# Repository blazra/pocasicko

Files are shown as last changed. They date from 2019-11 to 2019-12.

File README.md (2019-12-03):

# Počasíčko

LoRa node with e-paper display and BME680
- Murata CMWX1ZZABZ-091: Semtech SX1276 + STM32L072
- Bosch Sensortec BME680 measures pressure, humidity, temperature and Volatile Organic Compounds (VOC)
- Waveshare 4.2" EPD 400x300
- Powered from three AA batteries

Revision 1 known issues:
- Missing divider for battery voltage monitoring
- Unable to wake-up from standby using BUTTON_A (WKUP1), because pull-ups are disconnected in standby mode

[Schematic](./pcb/revision_1/pocasicko-schematic.pdf)

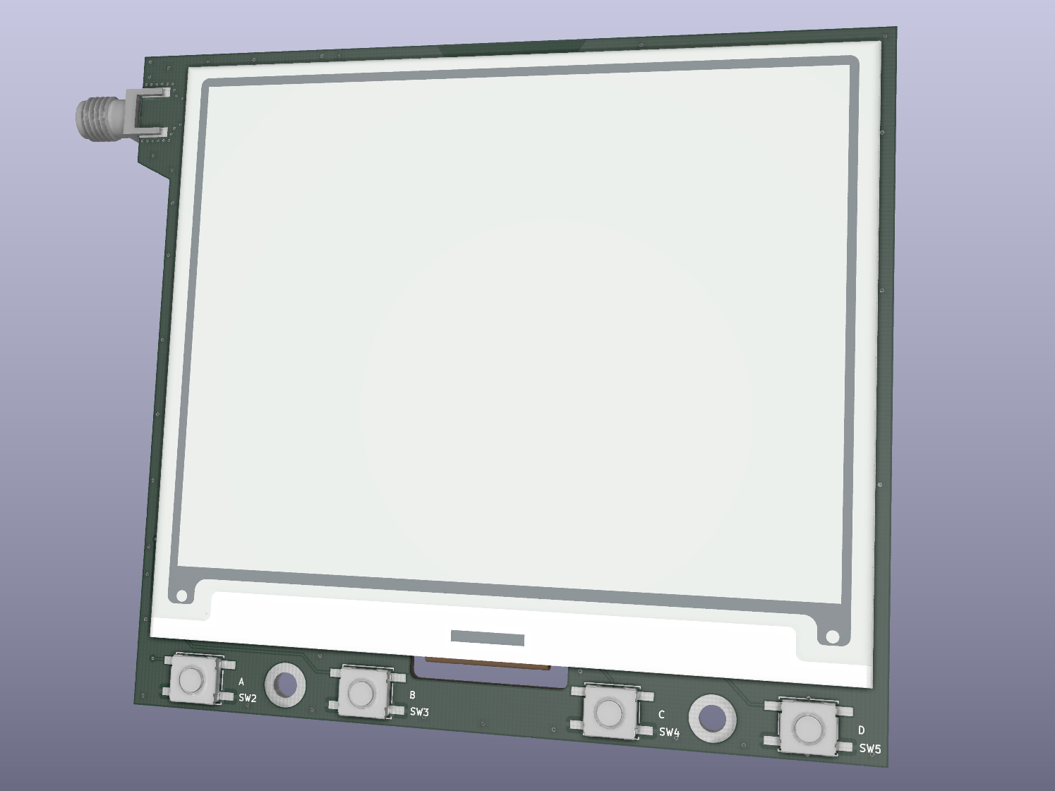
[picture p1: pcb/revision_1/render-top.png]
Front pcb render

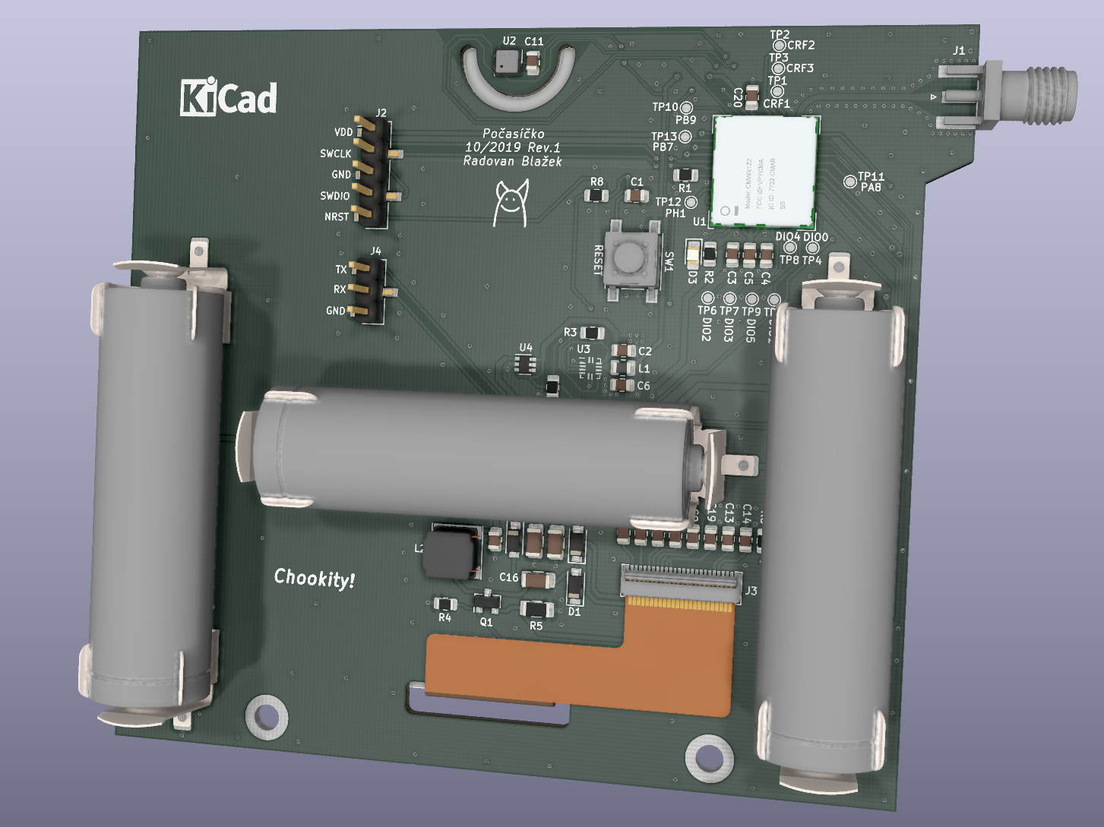
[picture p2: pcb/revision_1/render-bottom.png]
Back pcb render


---
Počasíčko means little weather in Czech

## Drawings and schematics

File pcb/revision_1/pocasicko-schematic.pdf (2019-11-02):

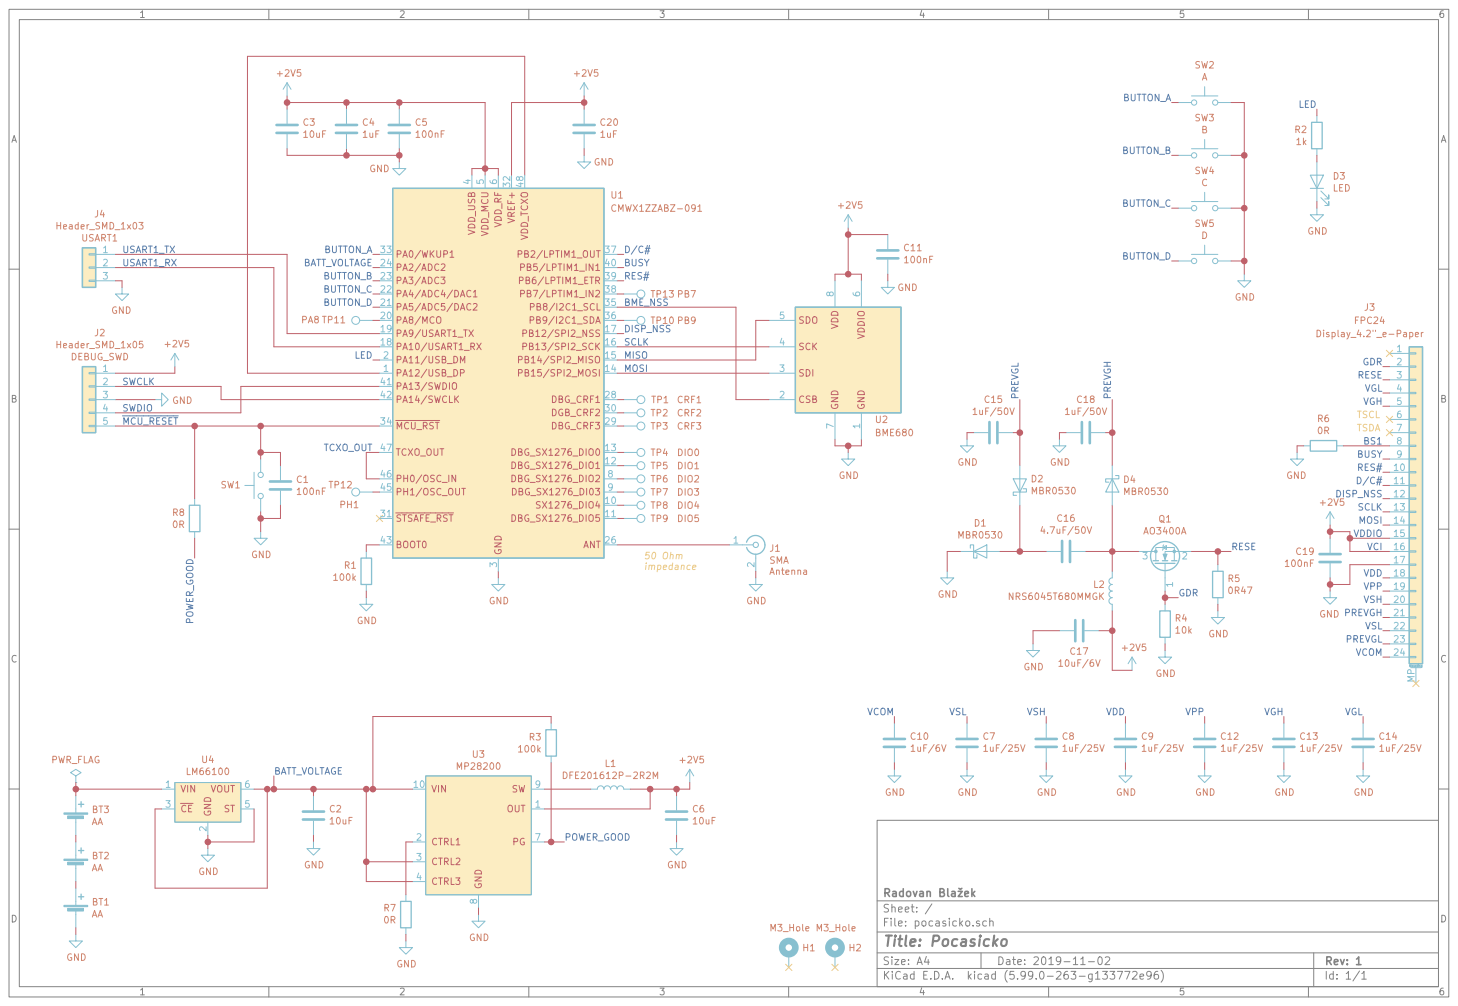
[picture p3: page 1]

1 CSB 2 SDI 3 SCK 4 SDO 5 VDDIO

File: pocasicko.sch Sheet: / Radovan Blaek GND

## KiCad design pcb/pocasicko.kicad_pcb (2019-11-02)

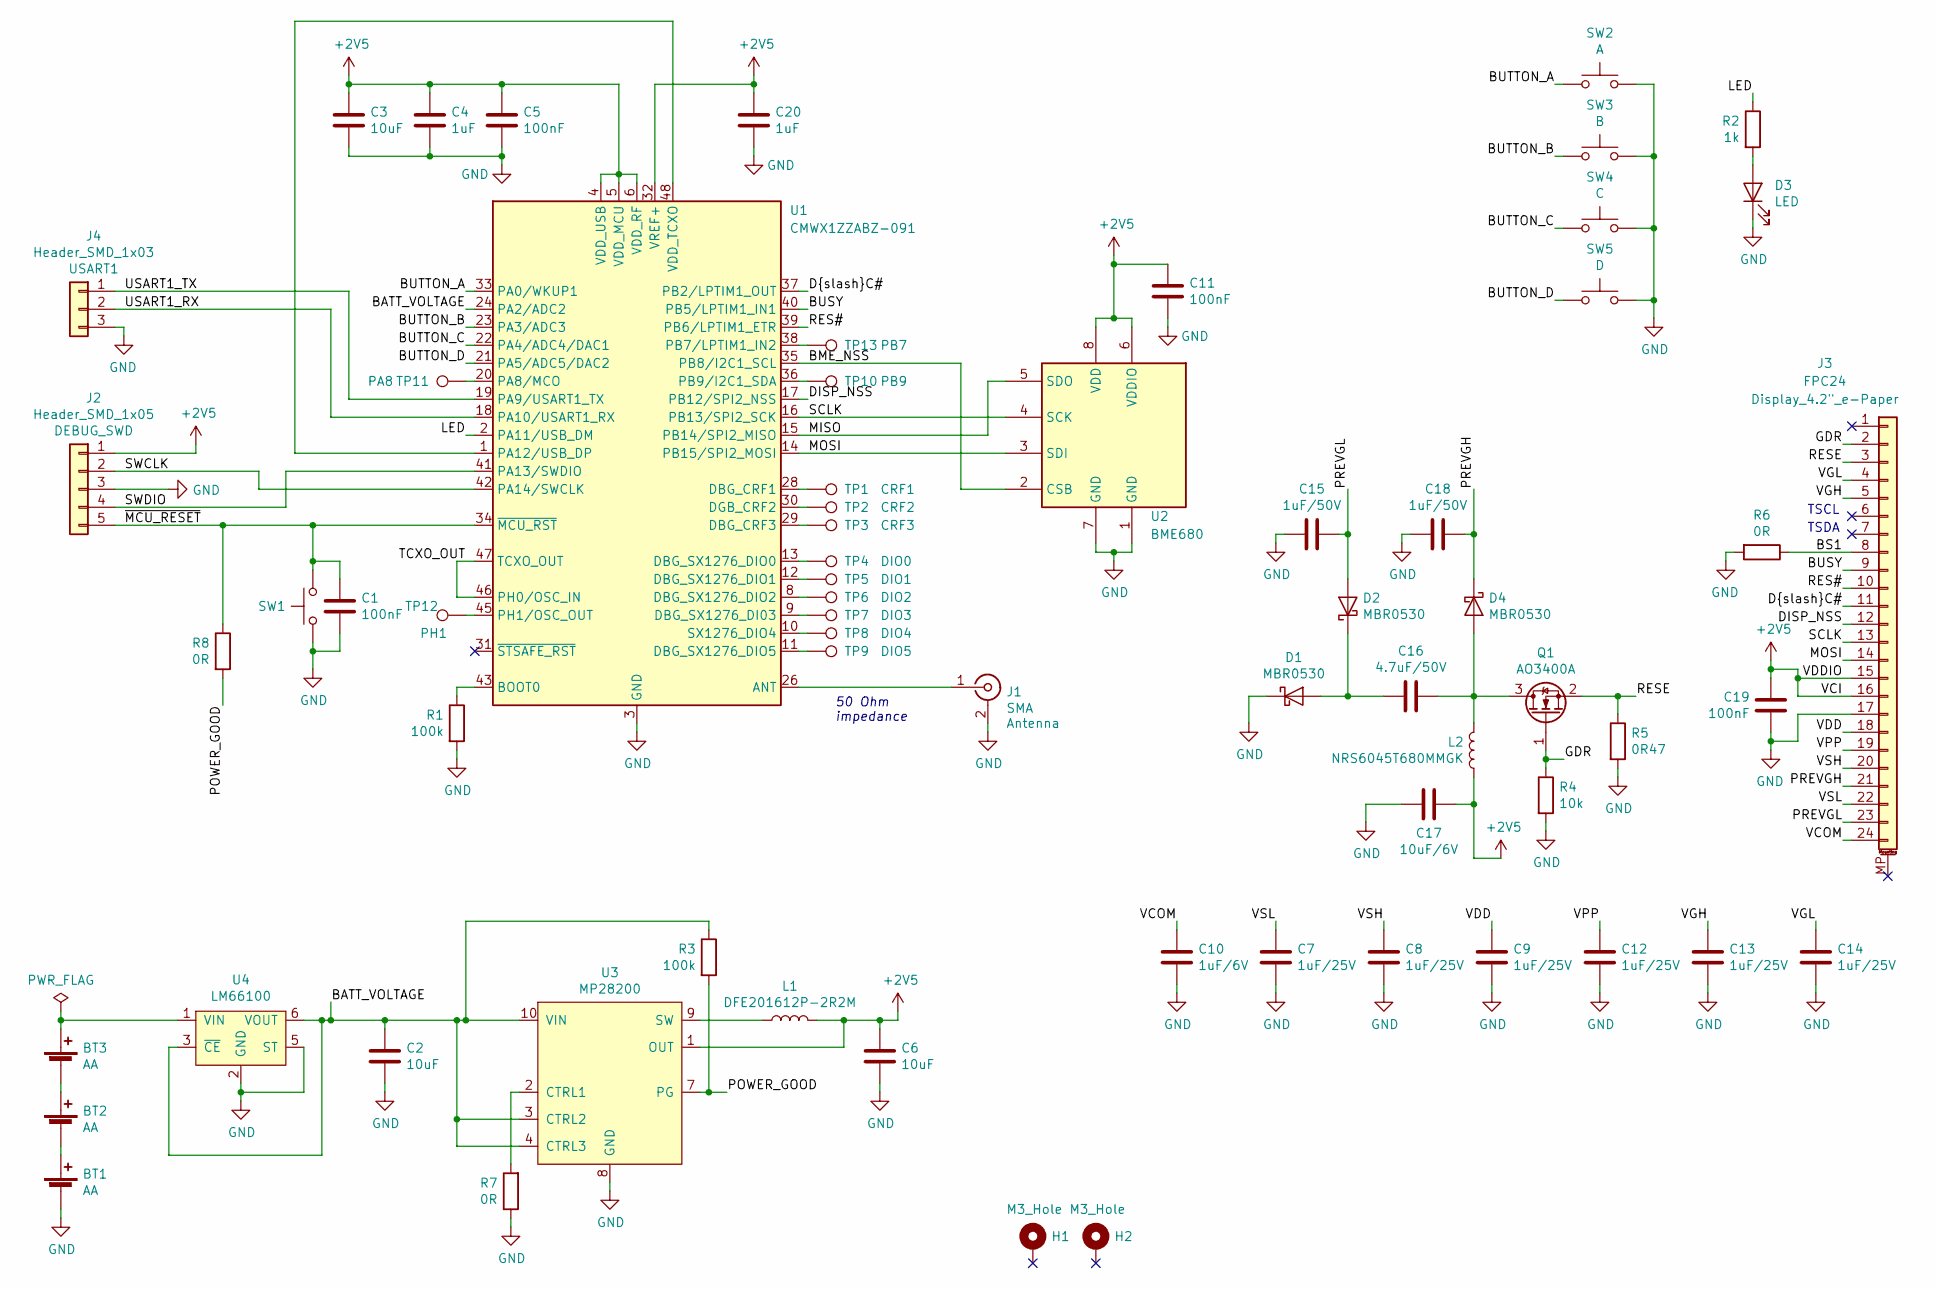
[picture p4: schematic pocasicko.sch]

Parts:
BT1, BT2, BT3: AA; BatteryHolder_Keystone_53_1xAA
C1, C5, C11, C19: 100nF; C_0805_2012Metric
C2, C3, C6: 10uF; C_0805_2012Metric
C4, C20: 1uF; C_0805_2012Metric
C7, C8, C9, C12, C13, C14: 1uF/25V; C_0805_2012Metric
C10: 1uF/6V; C_0805_2012Metric
C15, C18: 1uF/50V; C_1206_3216Metric
C16: 4.7uF/50V; C_1206_3216Metric
C17: 10uF/6V; C_0805_2012Metric
D1, D2, D4: MBR0530; D_SOD-123
D3: LED; LED_0805_2012Metric_Castellated
H1, H2: M3_Hole; MountingHole_3.2mm_M3_DIN965_Pad
J1: SMA; SMA_Samtec_SMA-J-P-H-ST-EM1_EdgeMount
J2: Header_SMD_1x05; PinHeader_1x05_P2.54mm_Vertical_SMD_Pin1Left
J3: FPC24; Waveshare_EPD_4.2_Amphenol_SFV24R-4STBE1HLF
J4: Header_SMD_1x03; PinHeader_1x03_P2.54mm_Vertical_SMD_Pin1Left
L1: DFE201612P-2R2M; L_0806_2016Metric
L2: NRS6045T680MMGK; L_Taiyo-Yuden_NR-60xx
Q1: AO3400A; SOT-23
R1, R3: 100k; R_0805_2012Metric
R2: 1k; R_0805_2012Metric
R4: 10k; R_0805_2012Metric
R5: 0R47; R_1206_3216Metric
R6, R7, R8: 0R; R_0805_2012Metric
SW1: RESET; SW_Push_1P1T_NO_6x6mm_H9.5mm
SW2: A; SW_SPST_EVQQ2
SW3: B; SW_SPST_EVQQ2
SW4: C; SW_SPST_EVQQ2
SW5: D; SW_SPST_EVQQ2
TP1: CRF1; TestPoint_Pad_D1.0mm
TP2: CRF2; TestPoint_Pad_D1.0mm
TP3: CRF3; TestPoint_Pad_D1.0mm
TP4: DIO0; TestPoint_Pad_D1.0mm
TP5: DIO1; TestPoint_Pad_D1.0mm
TP6: DIO2; TestPoint_Pad_D1.0mm
TP7: DIO3; TestPoint_Pad_D1.0mm
TP8: DIO4; TestPoint_Pad_D1.0mm
TP9: DIO5; TestPoint_Pad_D1.0mm
TP10: PB9; TestPoint_Pad_D1.0mm
TP11: PA8; TestPoint_Pad_D1.0mm
TP12: PH1; TestPoint_Pad_D1.0mm
TP13: PB7; TestPoint_Pad_D1.0mm
U1: CMWX1ZZABZ-091; CMWX1ZZABZ
U2: BME680; Bosch_LGA-8_3x3mm_P0.8mm_ClockwisePinNumbering
U3: MP28200; QFN-12_2x2_Pitch0.4mm
U4: LM66100; SOT-363_SC-70-6

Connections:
+2V5: C3.2, C4.2, C5.2, C6.2, C11.2, C17.2, C19.2, C20.2, J2.1, J3.15, J3.16, L1.2, L2.1, U1.4 (VDD_USB), U1.5 (VDD_MCU), U1.6 (VDD_RF), U1.32 (VREF+), U2.6 (VDDIO), U2.8 (VDD), U3.1 (OUT)
/BATT_VOLTAGE: C2.2, R3.1, U1.24 (PA2/ADC2), U3.3 (CTRL2), U3.4 (CTRL3), U3.10 (VIN), U4.3 (~CE), U4.6 (VOUT)
/BME_NSS: U1.35 (PB8/I2C1_SCL), U2.2 (CSB)
/BS1: J3.8, R6.1
/BUSY: J3.9, U1.40 (PB5/LPTIM1_IN1)
/BUTTON_A: SW2.1, U1.33 (PA0/WKUP1)
/BUTTON_B: SW3.1, U1.23 (PA3/ADC3)
/BUTTON_C: SW4.1, U1.22 (PA4/ADC4/DAC1)
/BUTTON_D: SW5.1, U1.21 (PA5/ADC5/DAC2)
/DISP_NSS: J3.12, U1.17 (PB12/SPI2_NSS)
/D/C#: J3.11, U1.37 (PB2/LPTIM1_OUT)
/GDR: J3.2, Q1.1 (G), R4.1
/LED: R2.1, U1.2 (PA11/USB_DM)
/MISO: U1.15 (PB14/SPI2_MISO), U2.5 (SDO)
/MOSI: J3.14, U1.14 (PB15/SPI2_MOSI), U2.3 (SDI)
/POWER_GOOD: R3.2, R8.2, U3.7 (PG)
/PREVGH: C18.1, D4.1 (K), J3.21
/PREVGL: C15.1, D2.2 (A), J3.23
/RES#: J3.10, U1.39 (PB6/LPTIM1_ETR)
/RESE: J3.3, Q1.2 (S), R5.1
/SCLK: J3.13, U1.16 (PB13/SPI2_SCK), U2.4 (SCK)
/SWCLK: J2.2, U1.42 (PA14/SWCLK)
/SWDIO: J2.4, U1.41 (PA13/SWDIO)
/TCXO_OUT: U1.46 (PH0/OSC_IN), U1.47 (TCXO_OUT)
/USART1_RX: J4.2, U1.18 (PA10/USART1_RX)
/USART1_TX: J4.1, U1.19 (PA9/USART1_TX)
/VCOM: C10.2, J3.24
/VDD: C9.2, J3.18
/VGH: C13.2, J3.5
/VGL: C14.2, J3.4
/VPP: C12.2, J3.19
/VSH: C8.2, J3.20
/VSL: C7.2, J3.22
/~MCU_RESET: C1.1, J2.5, R8.1, SW1.2, U1.34 (~MCU_RST)
GND: BT1.2 (-), C1.2, C2.1, C3.1, C4.1, C5.1, C6.1, C7.1, C8.1, C9.1, C10.1, C11.1, C12.1, C13.1, C14.1, C15.2, C17.1, C18.2, C19.1, C20.1, D1.1 (K), D3.1 (K), J1.2 (Ext), J2.3, J3.17, J4.3, R1.2, R4.2, R5.2, R6.2, R7.1, SW1.1, SW2.2, SW3.2, SW4.2, SW5.2, U1.3 (GND), U1.7 (GND), U1.25 (GND), U1.27 (GND), U1.44 (GND), U1.49 (GND), U1.50 (GND), U1.51 (GND), U1.52 (GND), U1.53 (GND), U1.54 (GND), U1.55 (GND), U1.56 (GND), U1.57 (GND), U2.1 (GND), U2.7 (GND), U3.5 (TP), U3.6 (TP), U3.8 (GND), U4.2 (GND), U4.5 (ST)
unnamed: BT1.1 (+), BT2.2 (-)
unnamed: BT2.1 (+), BT3.2 (-)
unnamed: BT3.1 (+), U4.1 (VIN)
unnamed: C16.1, D4.2 (A), L2.2, Q1.3 (D)
unnamed: C16.2, D1.2 (A), D2.1 (K)
unnamed: D3.2 (A), R2.2
unnamed: J1.1 (In), U1.26 (ANT)
unnamed: L1.1, U3.9 (SW)
unnamed: R1.1, U1.43 (BOOT0)
unnamed: R7.2, U3.2 (CTRL1)
unnamed: TP1.1, U1.28 (DBG_CRF1)
unnamed: TP2.1, U1.30 (DGB_CRF2)
unnamed: TP3.1, U1.29 (DBG_CRF3)
unnamed: TP4.1, U1.13 (DBG_SX1276_DIO0)
unnamed: TP5.1, U1.12 (DBG_SX1276_DIO1)
unnamed: TP6.1, U1.8 (DBG_SX1276_DIO2)
unnamed: TP7.1, U1.9 (DBG_SX1276_DI03)
unnamed: TP8.1, U1.10 (SX1276_DIO4)
unnamed: TP9.1, U1.11 (DBG_SX1276_DIO5)
unnamed: TP10.1, U1.36 (PB9/I2C1_SDA)
unnamed: TP11.1, U1.20 (PA8/MCO)
unnamed: TP12.1, U1.45 (PH1/OSC_OUT)
unnamed: TP13.1, U1.38 (PB7/LPTIM1_IN2)
unnamed: U1.1 (PA12/USB_DP), U1.48 (VDD_TCXO)

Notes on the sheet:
50 Ohm impedance
TSCL
TSDA

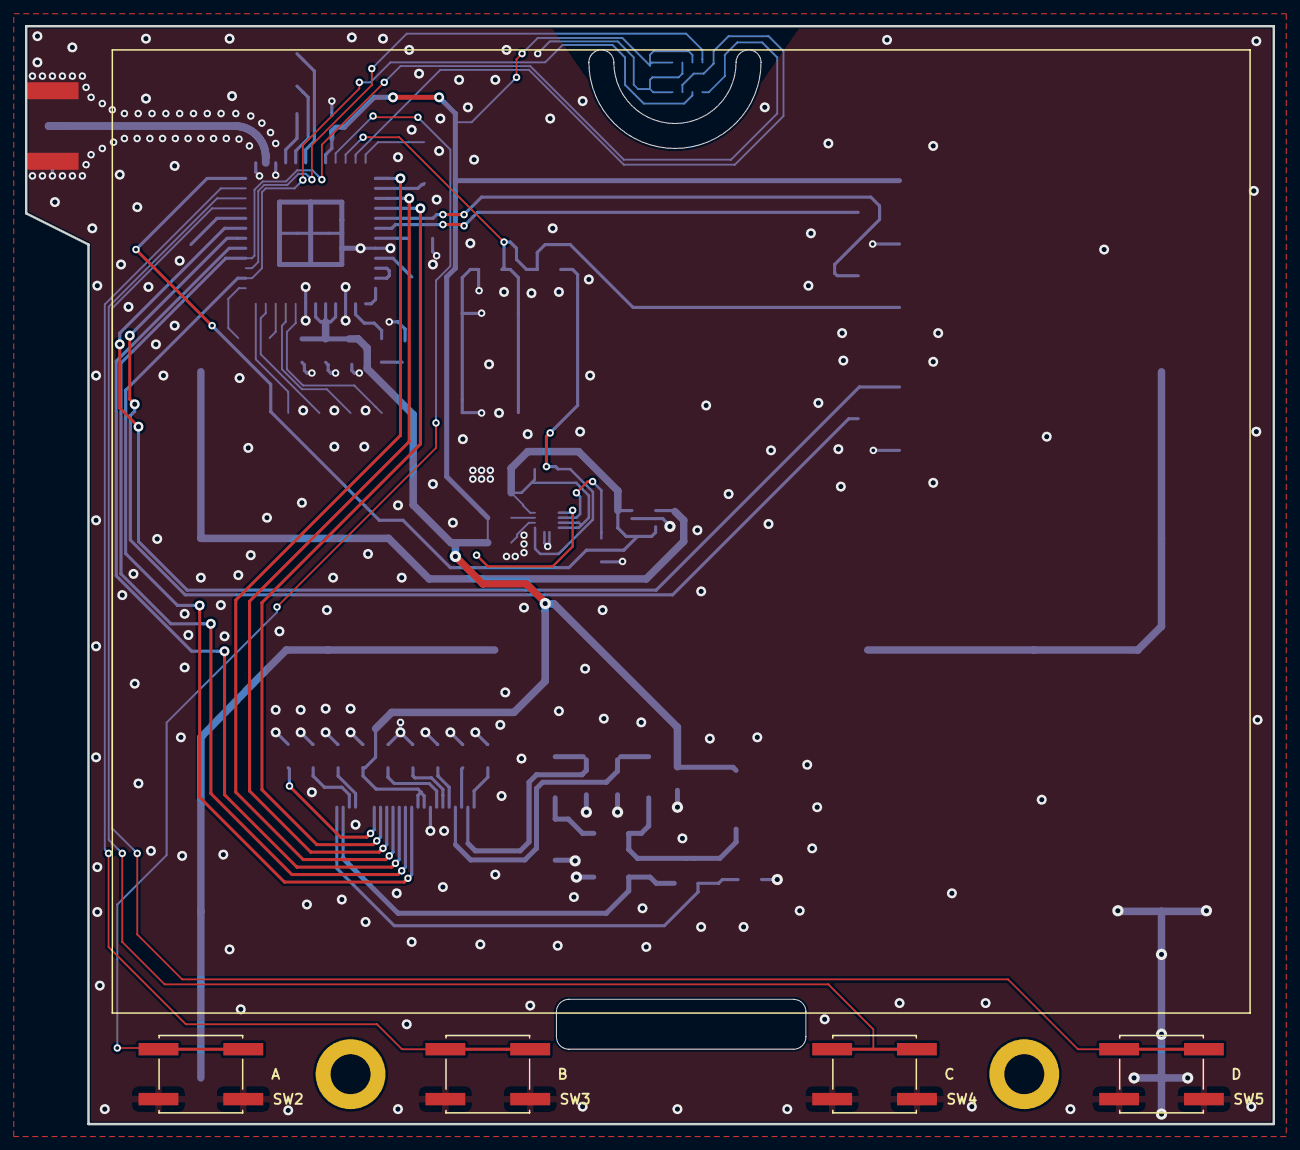
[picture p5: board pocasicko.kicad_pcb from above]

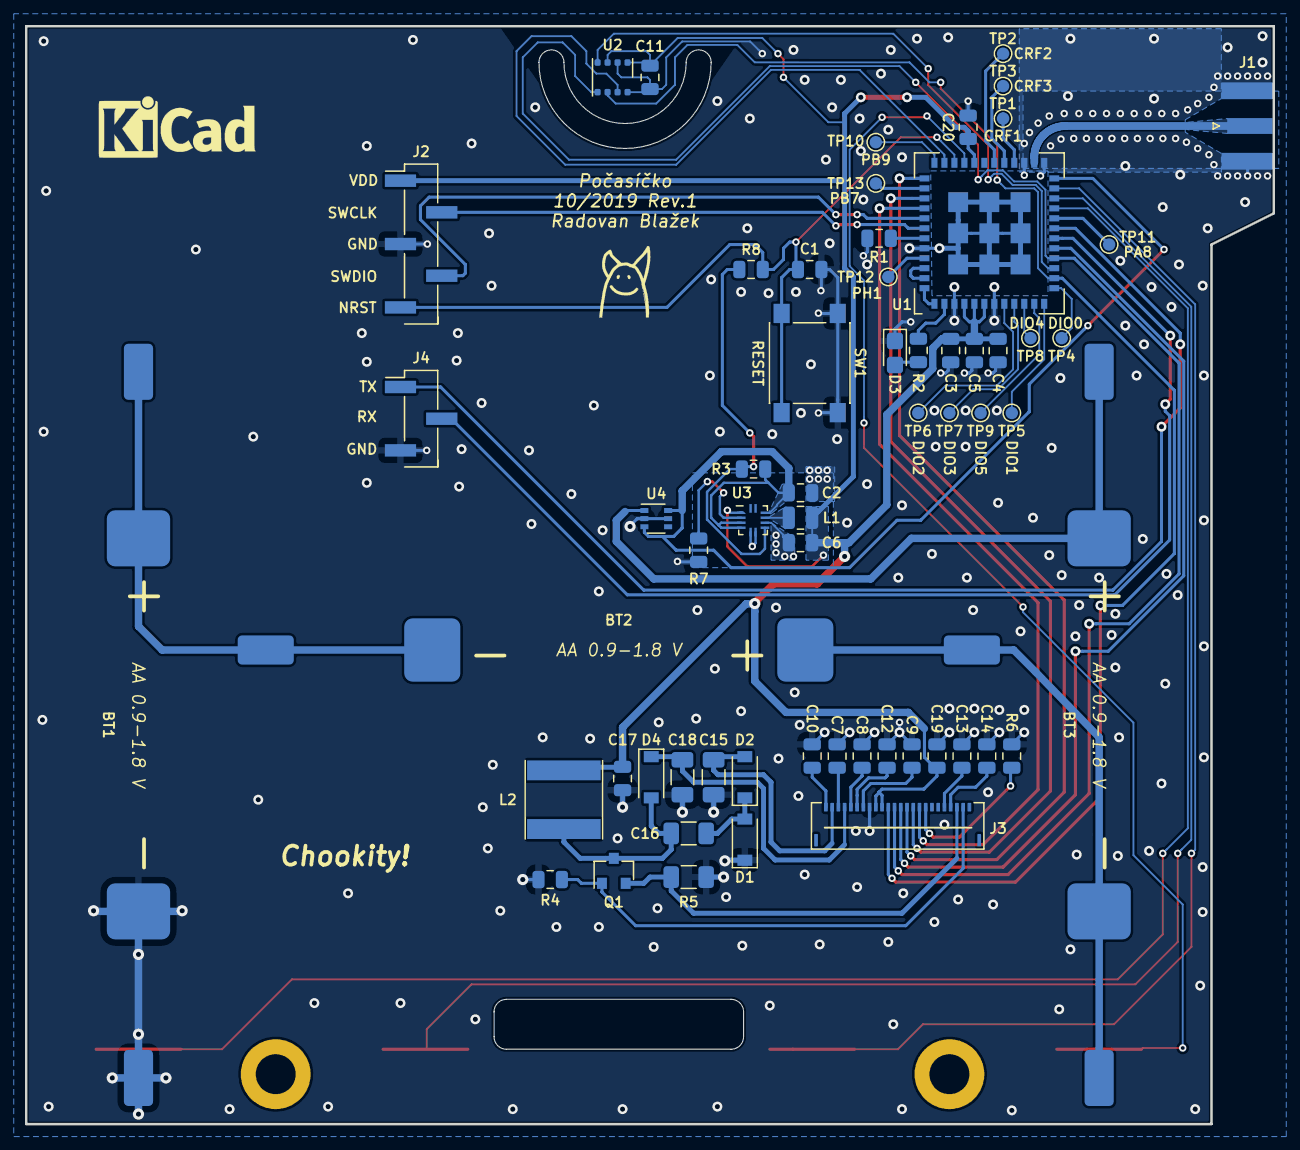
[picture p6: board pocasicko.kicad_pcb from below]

Board: 2 copper layers, 100.0 x 88.0 mm, 66 parts (60 on the bottom side), 59 nets.

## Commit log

2019-10-22 Finish schematic and large component placement
    All components chosen and placed on the PCB before routing and
    schematic probably mostly finished.
    [pocasicko.kicad_pcb, pocasicko.sch]
2019-10-22 Update README to reflect current design decisions
2019-10-27 Routing progress
    [pocasicko.kicad_pcb, pocasicko.sch]
2019-10-27 Rotate LoRa module
    [pocasicko.kicad_pcb]
2019-10-27 Rotate the center cell diagonally
    [pocasicko.kicad_pcb]
2019-10-29 Finished routing
    [pocasicko.kicad_pcb, pocasicko.sch]
2019-10-29 Exchange SMA and add groundplane to the back layer
    [pocasicko.kicad_pcb, pocasicko.sch]
2019-10-30 Change BME interface from I2C to SPI
    [pocasicko.kicad_pcb, pocasicko.sch]
2019-10-30 Enlarge the EPD flat flex hole
    [pocasicko.kicad_pcb]
2019-11-01 Exchanged FPC connector. This is the Rev. 1.
    [pocasicko.kicad_pcb]
2019-11-01 Add revision 1 gerbers
    [pocasicko-B_Mask.gbr, pocasicko-B_Paste.gbr, pocasicko-B_SilkS.gbr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]
2019-11-02 Add schematic pdf
    [pocasicko.sch]
2019-11-02 Rename schematic file
2019-11-02 Set footprints to use 3D models from ./packages3d/
    [pocasicko.kicad_pcb]
2019-11-02 Add revision 1 pcb renders
